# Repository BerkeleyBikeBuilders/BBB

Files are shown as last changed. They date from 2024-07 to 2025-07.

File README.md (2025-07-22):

# Telemetry Computer

## Description
This repository contains the HW and FW related to the ESP32 telemetry computer V1 (Fall 2023 - Fall 2024)

## Installation
1. Clone the repository:
   
    Go to the folder you want to clone to, and:
    ```bash
    git clone https://github.com/BerkeleyBikeBuilders/TelemetryComputer.git

3. Install IDE:
   
    **Platform IO on VS Code**
   
    Install Platform IO extension on VSCode, or the Arduino IDE online.

    **Arduino IDE**
   
    Install IDE from here: https://www.arduino.cc/en/software
   
    Add ESP32 boards this way: https://randomnerdtutorials.com/vs-code-platformio-ide-esp32-esp8266-arduino/
   
    If you prefer to use the Arduino IDE, to access the project, edit the 'telemetryINO' project, **and remember to first update the code from src/main.cpp**

4. install Libraries:
    I think it's only nessesary for the Arduino IDE.
    - Adafruit BusIO

6. select boards:
    Select either "Adafruit ESP32 Feather" or "WEMOS LOLIN32 Lite"

## Debugging
1. .............A fatal error occurred: No serial data received
   
   Try Changing to upload speed to 115200
   
   Try pressing the reset button, can also help clear processes that's preventing the upload (check your code).

![ESP32 WeMos LOLIN32 Lite Pinout](https://mischianti.org/wp-content/uploads/2021/07/ESP32-WeMos-LOLIN32-Lite-pinout-mischianti-low.jpg)

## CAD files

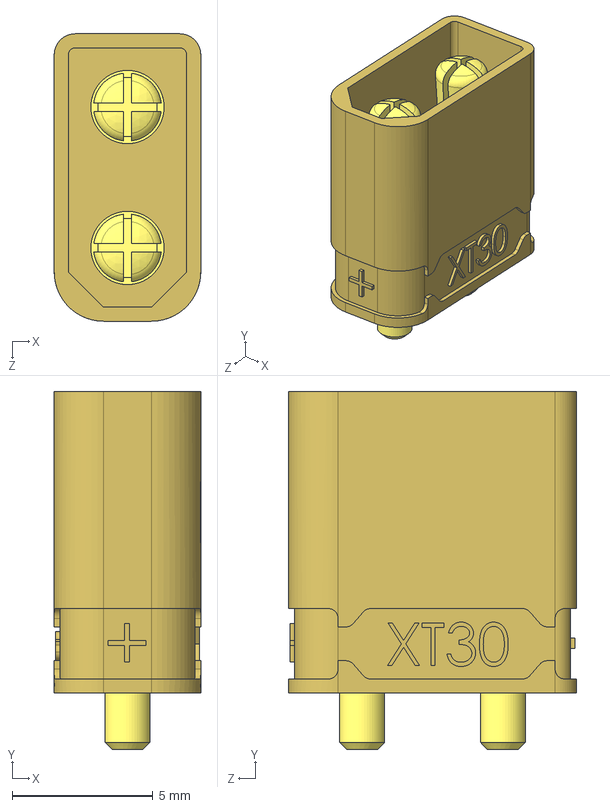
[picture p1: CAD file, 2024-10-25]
HW/adapter/components/LIB_XT30PB/XT30PB/3D/XT30PB.stp
5.20 x 12.7 x 10.2 mm

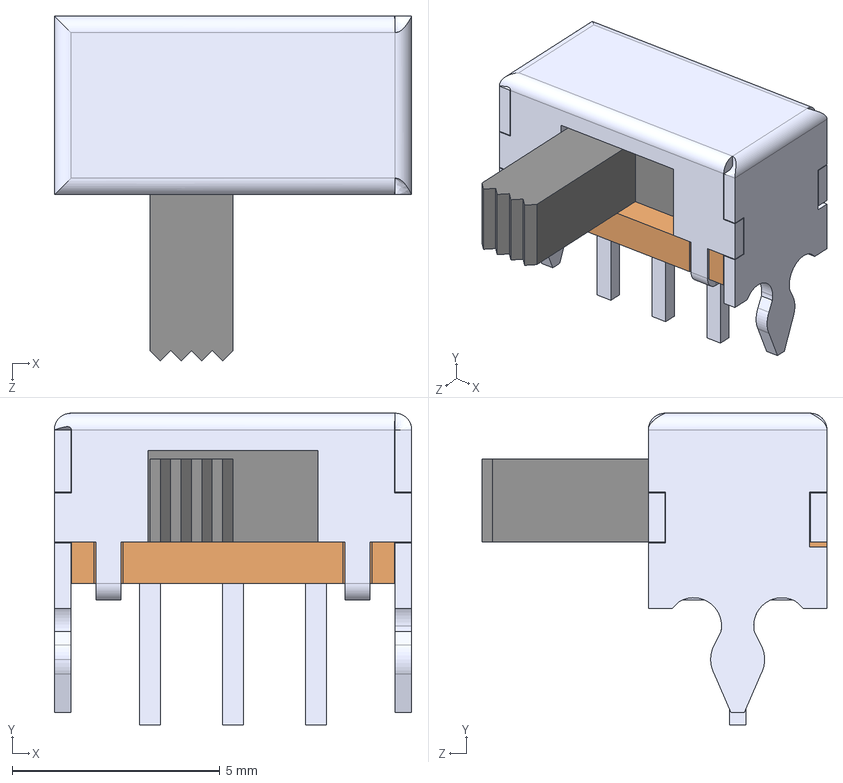
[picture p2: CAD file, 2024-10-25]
HW/TelemetryComputer/components/EG1247-2/EG1247.step
8.60 x 7.50 x 8.30 mm

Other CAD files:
HW/adapter/components/LIB_XT30PB/XT30PB/Allegro/xt30pb.psm
HW/adapter/components/LIB_XT30PB/XT30PB/DEHDL/xt30pb/chips/chips.prt
telemetryComputer_HW/adapter/components/LIB_XT30PB/XT30PB/Allegro/xt30pb.psm
telemetryComputer_HW/adapter/components/LIB_XT30PB/XT30PB/DEHDL/xt30pb/chips/chips.prt

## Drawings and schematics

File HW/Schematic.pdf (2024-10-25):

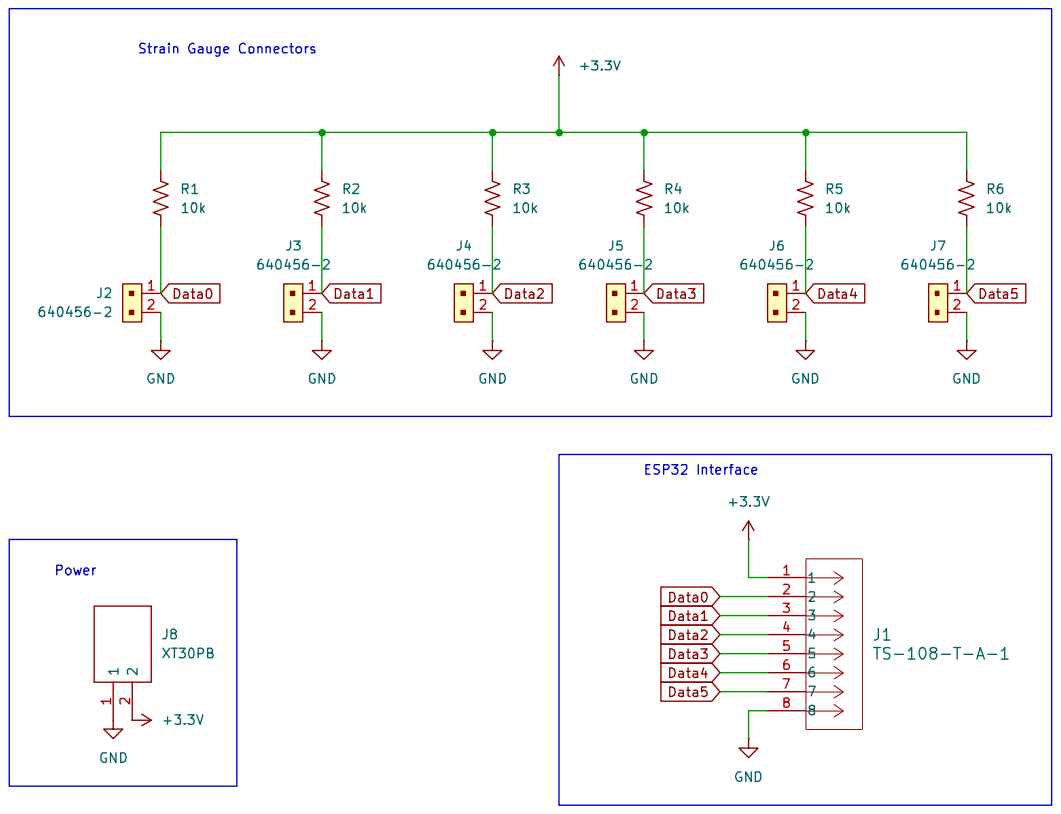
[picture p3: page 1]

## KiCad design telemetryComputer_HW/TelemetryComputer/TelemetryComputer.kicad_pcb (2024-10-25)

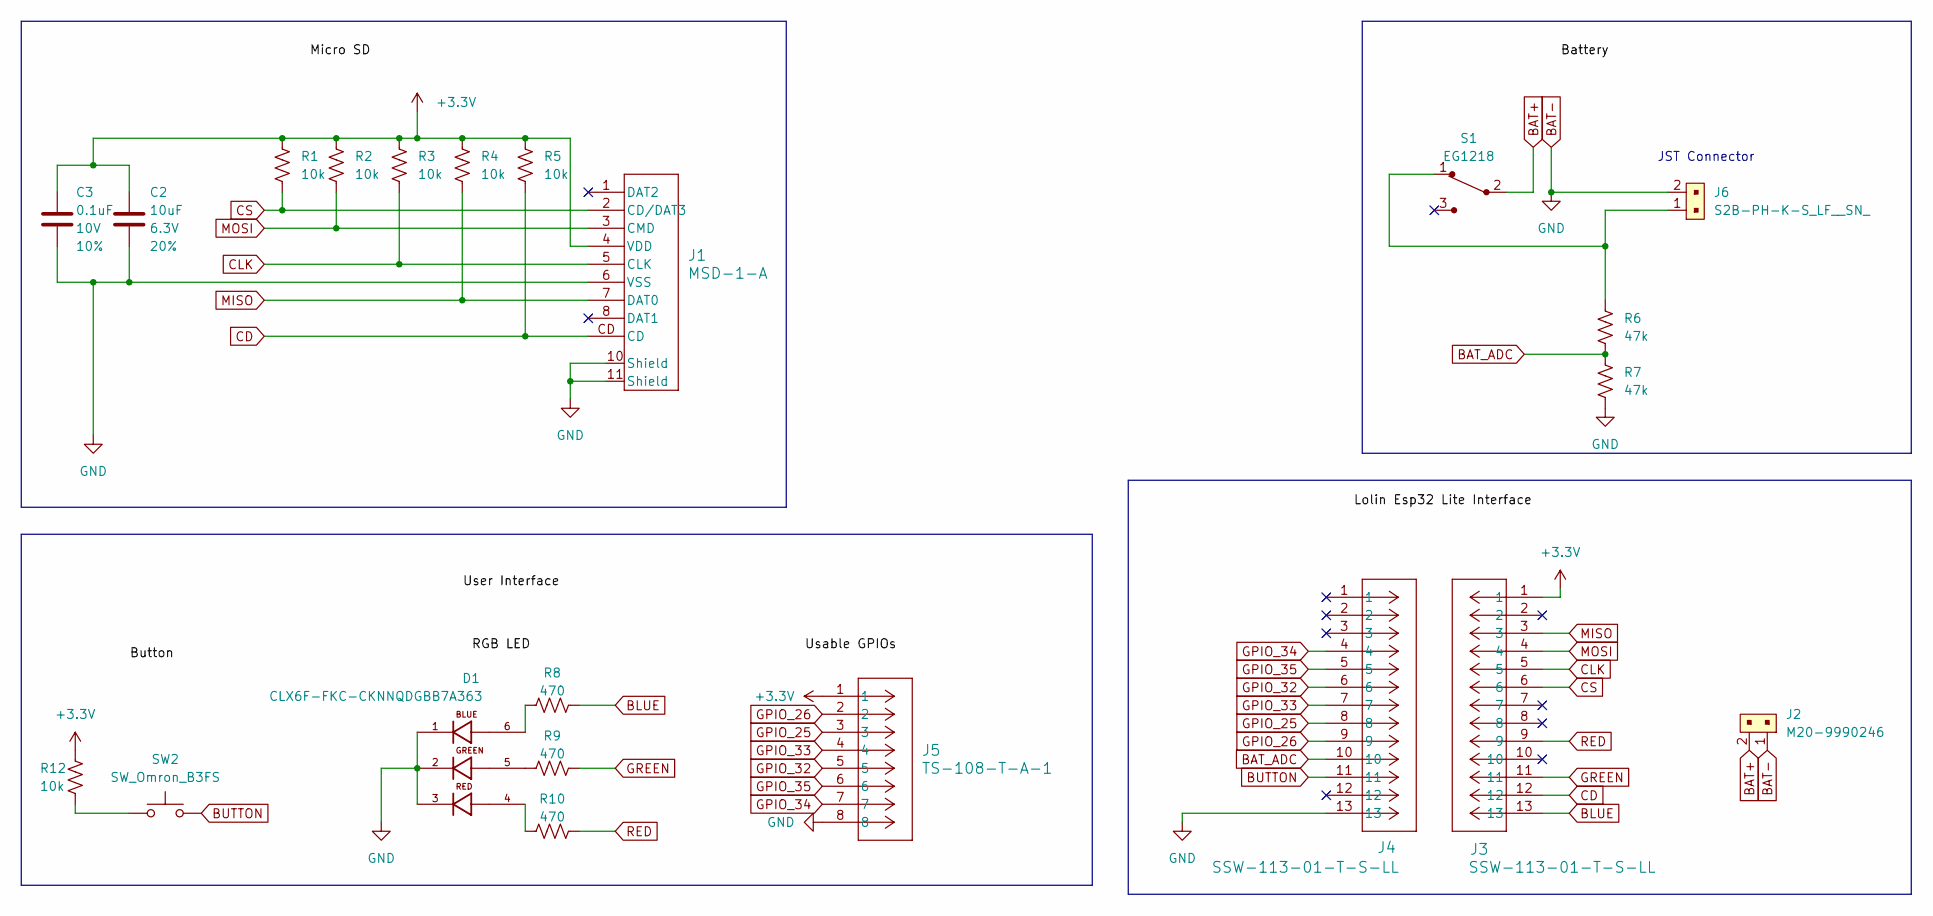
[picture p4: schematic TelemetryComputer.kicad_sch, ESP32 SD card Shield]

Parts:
C2: 10uF; C_0603_1608Metric; Voltage 6.3V; Tolerance 20%
C3: 0.1uF; C_0402_1005Metric; Voltage 10V; Tolerance 10%
D1: CLX6F-FKC-CKNNQDGBB7A363; SOJ100P350X290-6N; DigiKey_Part_Number CLX6F-FKC-CKNNQDGBB7A363TR-ND
J1: MSD-1-A; CONN9_MSD-1_CUD
J2: M20-9990246; PinHeader_1x2_P2.54mm; MPN M20-9990246; Digi-Key_PN 952-2262-ND
J3, J4: SSW-113-01-T-S-LL; CON13_1X13_TU_SSQ
J5: TS-108-T-A-1; CON8_1X8_TUC_HTS_SAI
J6: S2B-PH-K-S_LF__SN_; PinHeader_1x2_P2mm_Drill1mm_RA; MPN S2B-PH-K-S(LF)(SN); Digi-Key_PN 455-1719-ND
R1, R2, R3, R4, R5, R12: 10k; R_0603_1608Metric
R6, R7: 47k; R_0603_1608Metric
R8, R9, R10: 470; R_0603_1608Metric
S1: EG1218; Switch_Slide_11.6x4mm_EG1218; MPN EG1218; Digi-Key_PN EG1903-ND
SW2: SW_Omron_B3FS; SW_SPST_Omron_B3FS-100xP

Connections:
+3.3V: C2.1, C3.1, J1.4 (VDD), J3.1, J5.1, R1.1, R2.1, R3.1, R4.1, R5.1, R12.1
BAT+: J2.2, S1.2
BAT-: C2.2, C3.2, D1.1, D1.2, D1.3, J1.6 (VSS), J1.10 (Shield), J1.11 (Shield), J2.1, J4.13, J5.8, J6.2, R7.2
BAT_ADC: J4.10, R6.2, R7.1
BLUE: J3.13, R8.1
BUTTON: J4.11, SW2.2
CD: J1.CD, J3.12, R5.2
CLK: J1.5 (CLK), J3.5, R3.2
CS: J1.2 (CD/DAT3), J3.6, R1.2
GPIO_25: J4.8, J5.3
GPIO_26: J4.9, J5.2
GPIO_32: J4.6, J5.5
GPIO_33: J4.7, J5.4
GPIO_34: J4.4, J5.7
GPIO_35: J4.5, J5.6
GREEN: J3.11, R9.1
MISO: J1.7 (DAT0), J3.3, R4.2
MOSI: J1.3 (CMD), J3.4, R2.2
unnamed: D1.4, R10.2
unnamed: D1.5, R9.2
unnamed: D1.6, R8.2
unnamed: J6.1, R6.1, S1.1
unnamed: R12.2, SW2.1
RED: J3.9, R10.1

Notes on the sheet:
JST Connector

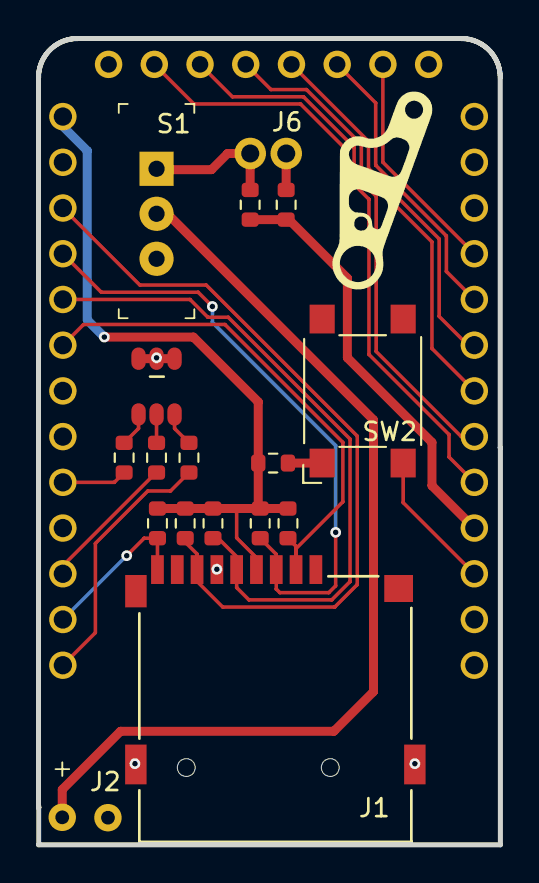
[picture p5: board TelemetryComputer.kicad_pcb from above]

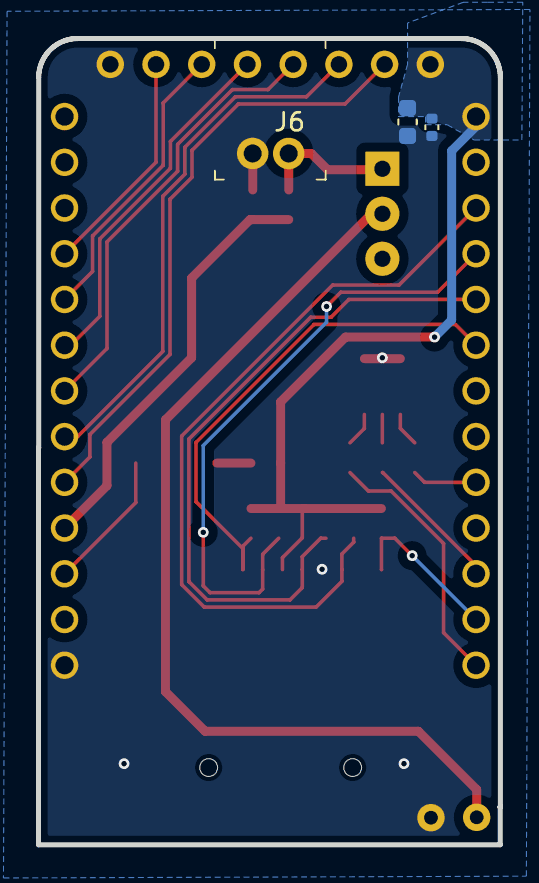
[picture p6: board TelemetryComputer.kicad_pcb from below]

Board: 2 copper layers, 25.7 x 44.8 mm, 22 parts (3 on the bottom side), 24 nets.

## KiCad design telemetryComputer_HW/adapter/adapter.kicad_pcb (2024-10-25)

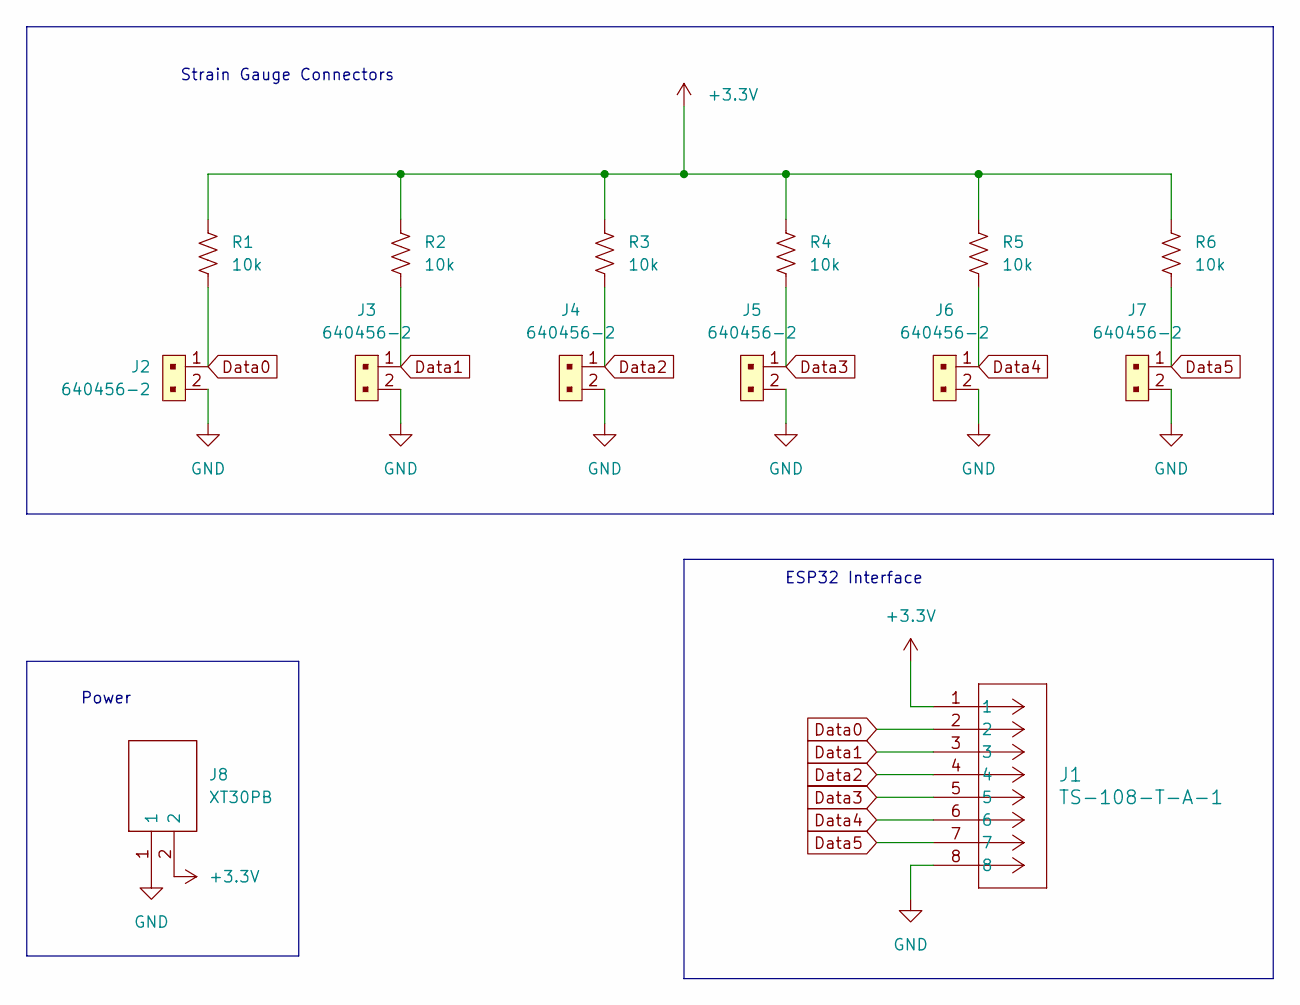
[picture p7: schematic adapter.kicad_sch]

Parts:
J1: TS-108-T-A-1; CON8_1X8_TUC_HTS_SAI
J2, J3, J4, J5, J6, J7: 640456-2; PinHeader_1x2_P2.54mm_Drill1.02mm; MPN 640456-2; Digi-Key_PN A1921-ND
J8: XT30PB; AMASS_XT30U-F_1x02_P5.0mm_Vertical; Manufacturer_Part_Number XT30PB
R1, R2, R3, R4, R5, R6: 10k; R_0603_1608Metric

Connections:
+3.3V: J1.1, J8.2, R1.1, R2.1, R3.1, R4.1, R5.1, R6.1
Data0: J1.2, J2.1, R1.2
Data1: J1.3, J3.1, R2.2
Data2: J1.4, J4.1, R3.2
Data3: J1.5, J5.1, R4.2
Data4: J1.6, J6.1, R5.2
Data5: J1.7, J7.1, R6.2
GND: J1.8, J2.2, J3.2, J4.2, J5.2, J6.2, J7.2, J8.1

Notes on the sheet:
Power
ESP32 Interface
Strain Gauge Connectors

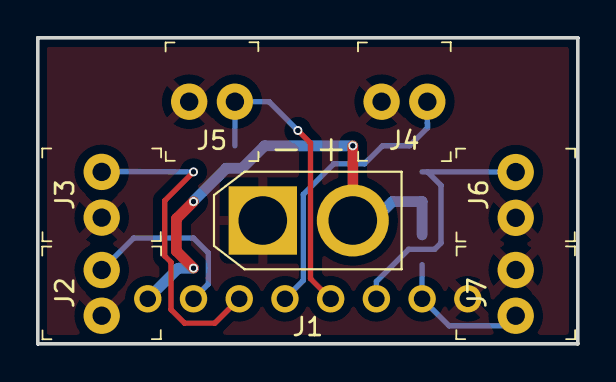
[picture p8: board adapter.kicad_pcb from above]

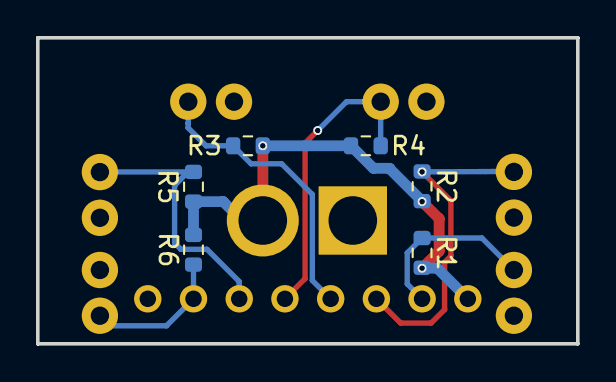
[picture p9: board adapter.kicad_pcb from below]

Board: 2 copper layers, 30.0 x 17.0 mm, 14 parts (6 on the bottom side), 8 nets.

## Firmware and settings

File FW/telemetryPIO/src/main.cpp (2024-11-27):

/**
 * * * * * * * * * * * * * * * * * * * * * * * * * * * * * * * * * * * * * * * * * *
 * @file main.cpp                                                                  *
 * @brief Code for the Telemetry Computer for the Bike Builders of Berkeley.       *
 *                                                                                 *
 * Hello! I hope you'll have as much fun working on this as I did!                 *
 *                                                                                 *
 * Started in Fall 2023, the Telemetry Computer will be transformed into a         *
 * general, modular test platform to inform the new mountain bike design           *
 * project in Fall 2024!                                                           *
 *                                                                                 *
 * Bike Builders of Berkeley is a student club at UC Berkeley.                     *
 *                                                                                 *
 * @author Kevin Ying, Ziven Posner, Grant Hough                                   *
 * @date 22 August, 2024                                                           *
 *                                                                                 * 
 * @details It relies on the Arduino core libraries and these custom header        * 
 *          files:                                                                 *
 *              Buttons.h                                                          *
 *              LED.h                                                              *
 *              LED_Behaviors.h                                                    *
 *              Battery.h                                                          *
 *              SD_ReadWrite.h                                                     *
 * * * * * * * * * * * * * * * * * * * * * * * * * * * * * * * * * * * * * * * * * *
 */

#include <Arduino.h>
#include <driver/rtc_io.h>

// USER INTERFACE
#include "Buttons.h"
#include "LED.h"
#include "LED_Behaviors.h"
#include "Strain_Gauge_Calibration.h"
LED led; // Declares a global LED instance
Button button; // Declares a global Button instance

enum UserInterfacePins {
  BUTTONPIN = 27,
  RPIN = 4,
  GPIN = 2,
  BPIN = 13,
};

// POWER SUPPLY
#include "Battery.h"
const int batteryPin = 15;
BatteryVoltageSensor battery;

// Sleep:
int sleepCounter = 0;

// INPUT SOCKETS
enum InputSockets {
  PIN1 = 25,
  PIN2 = 26,
  PIN3 = 33,
  PIN4 = 32,
  PIN5 = 35,
  PIN6 = 34,
};

// SD CARD
#include "SD_ReadWrite.h"
#define MISO 19
#define SCK 18
#define MOSI 23
#define CS 5
String startMessage  = "Time (secs),Fork Position";     // The "\n" are added in the methods, so new columns can be easily added.
String stopMessage;
String resumeMessage;
String pauseMessage  = "Paused, Paused, Paused, Paused, Paused"; // Make sure that the number of commas is the same as the number of columns! 3 columns
String recordingMessage;
const int DELAY = 10; // optional delay between each run
const int SLEEP_THRESHOLD = 6000; // 6000 * ~10 miliseconds ≈ 1 minute.

void setup() {
  Serial.begin(9600); // Starts Serial communication.

  // USER INTERFACE
  led.create(RPIN, GPIN, BPIN);
  led.calibrateBrightness(0.05F);
  button.create(BUTTONPIN, led);
  button.customiseButtonMessage(startMessage, stopMessage, resumeMessage, pauseMessage); // The messages will be written into the csv file.

  // POWER SUPPLY
  battery.create(batteryPin);
  battery.displayBattery(led); // Shows battery status when turned on.

  // Sleep:
  rtc_gpio_deinit((gpio_num_t) BUTTONPIN); // Revert the rtc_GPIO wake up pin back to a normal (digital?) GPIO.
  //sry I used casting...

  // INPUT SOCKETS


  for (int pin = PIN1; pin <= PIN6; ++pin) {
      pinMode(pin, INPUT);
  }

  // pinMode(PIN1, INPUT);
  // pinMode(PIN2, INPUT);
  // pinMode(PIN3, INPUT);
  // pinMode(PIN4, INPUT);
  // pinMode(PIN5, INPUT);
  // pinMode(PIN6, INPUT);

  // SD CARD
  while (!sdMount(SCK, MISO, MOSI, CS)) {
    thinking(led);
  } 
  confirm(led);
}

void loop() {
  // Add a delay to prevent too much output (optional)
  delay(DELAY);
  Serial.println(button.buttonReading());

  //CSV file for one strain gauge will need to adjust for multiple gauges
  if (button.isRecording()) {
    Serial.println("Recording!");
    sleepCounter = 0;

    double currentStrain1 = readStrainGauge(strainPin1);
    double adjustedStress1 = convertStrainToStress(currentStrain1, baselineStrain[0]);
    double currentStrain2 = readStrainGauge(strainPin2);
    double adjustedStress2 = convertStrainToStress(currentStrain2, baselineStrain[1]);
    double currentStrain3 = readStrainGauge(strainPin3);
    double adjustedStress3 = convertStrainToStress(currentStrain3, baselineStrain[2]);


    recordingMessage = String(millis() / 1000.0) + "," + 
    String(currentStrain1) + "," + String(adjustedStress1) + "," + 
    String(currentStrain2) + "," + String(adjustedStress2) + "," +
    String(currentStrain3) + "," + String(adjustedStress3); // You can append new columns here (modify 'pauseMessage' line 21 if you do).
    
    appendFile(recordingMessage + "\n");

  } else {
    //Serial.println("Not recording.");

    sleepCounter++;
    if (sleepCounter > SLEEP_THRESHOLD) { 
      Serial.println("I'm going to sleep (=_=)");
      sleep(led); // plays sleep animation
      delay(100);

      esp_sleep_enable_ext0_wakeup((gpio_num_t) BUTTONPIN, HIGH); // Assigning the button as the wake up pin. sry again for using casting.
      esp_deep_sleep_start();
    }
  }
}

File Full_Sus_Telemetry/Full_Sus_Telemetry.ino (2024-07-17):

// BATTERY
#include "Battery.h"
const int batteryPin = 15;
const float compensator = batteryFactor(); // this compensates for the voltage error from the ESP board's internal impedance

// BUTTONS
#include "Buttons.h"
const int buttonPin = 27;
// gpio_num_t buttonSleepPin = gpio_num_t(buttonPin);
String startMessage = "Time (secs),Fork Position"; // the "\n" is added via the function so new columns can be easily added.
String stopMessage = "";                           // left empty for now
String resumeMessage = "";
String pauseMessage = "Paused, Paused";
String recordingMessage;

// LED
#include "LED.h"
#include "LED_Behaviors.h"
const int RPIN = 3;
const int GPIN = 0;
const int BPIN = 4;
LED led; // initiates the LED object

// LINEAR POTENTIOMETER
// #include "Potentiometer.h"
// LPOT forkMeter;
// const int forkPin = 35;
// const float forkLength = 200;
// float forkPosition;
// LPOT shock_meter;
// const int shock_pin = 17;
// const float shock_length = 200;
// float shockPosition;

// EXPANSION BUS
const int bus1 = 25;
const int bus2 = 26;
const int bus3 = 33;
const int bus4 = 32;
const int bus5 = 35;
const int bus6 = 34;

// SD CARD
#include "SD_ReadWrite.h"
#define MISO 19
#define SCK 18
#define MOSI 23
#define CS 5

// MISC

void setup() {
  // Initialize Serial communication at a baud rate of 115200
  Serial.begin(9600);

  // LED
  led.create(RPIN, GPIN, BPIN);
  //led.calibrateBrightness(0.3, 0. 5, 0.5);

  // BATTERY
  pinMode(batteryPin, INPUT);
  float voltage = readVoltage(compensator, batteryPin);
  displayBattery(led, voltage); // shows battery status when turned on.

  // SD CARD
  while (!sdMount(SCK, MISO, MOSI, CS)) {
    thinking(led);
  } 
  confirm(led);

  // BUTTON
  pinMode(buttonPin, INPUT);
  customiseButtonMessage(startMessage, stopMessage, resumeMessage, pauseMessage);

  // LINEAR POTENTIOMETER
  //forkMeter.create(forkPin, forkLength);
  // shock_meter.create(shock_pin, shock_length);
}

void loop() {
  // Add a delay to prevent too much output (optional)
  delay(10);
  buttonReading(buttonPin, led);
  Serial.println();

  if (isRecording()) {
    //forkPosition = forkMeter.read();
    //Serial.println(forkPosition);
    recordingMessage = String(millis() / 1000.0) + "," + String("data entry"); // you can append new columns here

    appendFile(recordingMessage + "\n");
  } else {
    //while the device isn't doing anything memory-intensive:
    // sleepTimer++;
    // if (sleepTimer > 50000) {
    //   esp_sleep_enable_ext0_wakeup(buttonSleepPin, 1); // sleep until button is pressed
    //   esp_deep_sleep_start();
    // }
  }

  //   if (digitalRead(sdStatus) == HIGH)
  //   {
  //     while (!sdMount(SCK, MISO, MOSI, CS))
  //     {
  //       thinking(led);
  //     }
  //     confirm(led);
  //   }
  // }
}

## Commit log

2023-12-15 Added code so far for ESP32
2023-12-15 Arduino files so far
2024-01-27 Bru if this doesn't work...
    [Battery.h, LED.h, LED_Behaviors.h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]
2024-07-06 SD card corrected to VSPI pins
    MOSI: Pin 23
    MISO: Pin 19
    CLK: Pin 18
    CS: Pin 5
    [Full_Sus_Telemetry.ino, LED.h]
2024-08-28 Revert "Ready for Fall 2024!"
    This reverts commit a9809f8729a649ef2c50adf7f5f72ee82b5d9a48.
    [LED.h]
2024-08-28 Reapply "Ready for Fall 2024!"
    This reverts commit e58cfe65e1959bf659cb108c39cd2d223e135f0e.
    [LED.h]
2024-10-25 added PCB schematic
2024-10-25 added more KiCAD stuff
    [EDI2CAP.CFG, EG1247.step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]
2024-11-07 added mock data
    [mock_data.csv]
2024-11-11 made calibration its own thing
2025-07-22 reorganised files
    [EDI2CAP.CFG, EG1247.step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]
2025-07-22 more reorgnaising
    [EDI2CAP.CFG, EG1247.step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]
2025-07-23 moved things
    [EDI2CAP.CFG, EG1247.step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]
2025-07-23 reverted changes
    [EDI2CAP.CFG, EG1247.step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]
